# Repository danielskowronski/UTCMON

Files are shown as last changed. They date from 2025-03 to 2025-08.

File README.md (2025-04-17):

# UTCMON

Dual-screen clock intended designed mounting on top of *mon*itor (with USB camera in between), intended for displaying *UTC* and local time with proper NTP synchronization.

Project is baed on ESP32 for networking and 3.12" 256x64 OLED displays to match height of Logitech C920 camera. It'll additionaly include 3D printed cases for displays and central unit, light sensor for brightness, minimalistic physical controls and APIs for automation.

---

## Terminology, general ideas and assumptions

- Entire device consists of three units - 2 displays (left and right, both housing identical set of sensors, one large display and connector) and central unit (with ESP32 dev board, connectors and USB-C cable for power, debug and flashing).
- Display units are symmetrical in Y axis, intended to be placed in one line on top of computer monitor, separated by webcam, which is not part of the project. Connectors should be on inner edge of display units.
- This is a one-off, so standards are ajusted for prototype. No proper PCB is planned at this time.

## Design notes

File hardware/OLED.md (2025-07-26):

# OLED - 256x64 with SSD1322

- Controller: SSD1322
- OLED Display 3.12" 256*64 25664 Dots Graphic LCD Module Display Screen LCM Screen SSD1322 Controller Support SPI
- https://www.aliexpress.com/item/1005007321062605.html
- datasheet of controller: https://www.displayfuture.com/Display/datasheet/controller/SSD1322.pdf
- comes configured as parallel 80XX, using here as "4SPI" so need to swap jumper from R6 to R5
- SPI connection from ESP32 works with frequencies up to 39.999 MHz

## PINS used

- 01: 3V3
- 02: GND
- 03: SCLK
- 05: SDI/MOSI
- 14: DC (data/command)
- 15: RESET
- 16: CS (chip select)

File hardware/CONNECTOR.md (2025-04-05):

# Connector between L/R display boards and main MCU board

The connector is IDC10, one per display board.

Colour of pin on drawing = colour of Kynar cable on board and Dupont wires on prototype phase.

For pins split in two:

- bottom half is Kynar/Dupont colour
- top half is alternative colour on hand drawn schematics

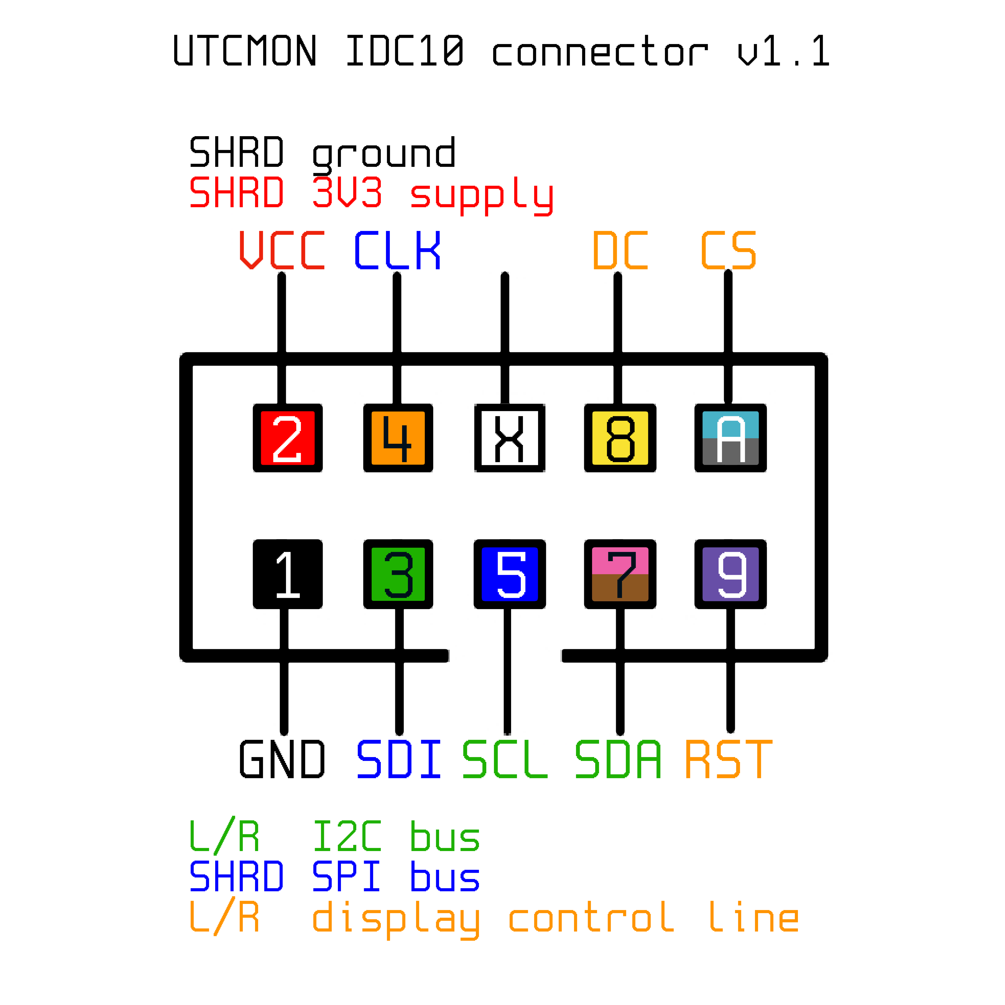
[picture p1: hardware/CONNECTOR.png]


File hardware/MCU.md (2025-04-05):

# MCU - ESP32S

- ID in Arduino: `NodeMCU-32S`
- ESP32S-CP2102-TYPE C (38pin)
- https://www.aliexpress.com/item/1005006161858012.html?spm=a2g0o.order_list.order_list_main.11.74fb1802DASUqN

## pin numbers for buses

- 18: VSPI SCLK
- 23: VSPI MOSI/SDI

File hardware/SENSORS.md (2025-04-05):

# Sensors

- all current sensors use I2C
- each display board (left and right) use separate I2C bus as one sensor (VL53L0X) has no hardware control; moreover two some separate lines for displays are needed anyway and ESP32 has two I2C

Buses:

- LEFT:
  - SDA: 21
  - SCK: 22
- RIGHT:
  - SDA: 32
  - SCK: 33

## Light sensor - TSL2561

- 2x TSL2561 - one per board
- I2C address 0x39 on both
- oriented towards top of unit
- used to set display brightness by averaging lux value and adjusting to 0..255 arnge

## Luminosity sensor - VL53L0X

- 2x VL53L0X - one per board
- I2C address 0x52 on both
- oriented towards front of unit
- used as touchless buttons (to avoid pushing displays from monitor) and primitive presence sensor

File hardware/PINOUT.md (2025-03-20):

# PINOUT

## prototype phase

common SPI bus for both displays:

- 3V3
- GND
- SCLK
- SDI/MOSI

1st display:

- DC => GPIO 00
- RESET => GPIO 04
- CS => 05

2nd display:

- DC => 02
- RESET => GPIO 16
- CS => 17

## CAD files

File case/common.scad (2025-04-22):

include <BOSL2/std.scad>
include <BOSL2/screws.scad>

$fa = 1;
$fs = 0.5;
$fn=36;

back_board_screw_dia=2;
back_board_screw_offset=1.75; //2?
back_board_thickness=1.5;

module base_plate_screw(){
    //TODO: autolmate offset
//    cylinder(wall_thickness, back_board_screw_dia/2, back_board_screw_dia/2);
    color("red")
    translate([0,0,wall_thickness+rnd/3])
    screw_hole("M2,10",head="flat",counterbore=0,anchor=TOP);
}

module base_plate(x_offset=0){
    difference(){
        cuboid([total_width, total_height, wall_thickness], anchor=[-1,-1,-1], rounding=rnd, edges=[TOP, "Z"]); // main front/back
        //cube([total_width, total_height, wall_thickness]); // main front/back

        translate([(total_width-back_board_width)/2+back_board_screw_offset+x_offset,(total_height-back_board_height)/2+back_board_screw_offset,0]) base_plate_screw(); 
        translate([(total_width+back_board_width)/2-back_board_screw_offset+x_offset,(total_height-back_board_height)/2+back_board_screw_offset,0]) base_plate_screw();
        translate([(total_width-back_board_width)/2+back_board_screw_offset+x_offset,(total_height+back_board_height)/2-back_board_screw_offset,0]) base_plate_screw();
        translate([(total_width+back_board_width)/2-back_board_screw_offset+x_offset,(total_height+back_board_height)/2-back_board_screw_offset,0]) base_plate_screw();

    }

}

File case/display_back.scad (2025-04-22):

include <display_common.scad>;

module display_back(){
    base_plate();
    
    //top wall
    translate([wall_thickness,0,-bottom_wall_top]) {
        difference(){
            cube([total_width-2*wall_thickness,wall_thickness, bottom_wall_top]);
            translate([(total_width-back_board_width)/2+lux_sensor_board_offset_from_back_board_x-wall_thickness,wall_thickness-lux_sensor_board_problematic_deth,0])
                color("red")cube([lux_sensor_board_width, lux_sensor_board_problematic_deth,bottom_wall_top ]);
        }
    }
    
    //right wall
    translate([total_width-wall_thickness,0,-bottom_wall_right]) {
        //cube([wall_thickness,total_height-wall_thickness, bottom_wall_right]);
        cuboid([wall_thickness,total_height-wall_thickness, bottom_wall_right], anchor=[-1,-1,-1], rounding=rnd, edges=[FRONT+RIGHT]);
        }
        
}

display_back();

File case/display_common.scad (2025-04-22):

include <common.scad>

// design for LEFT display board, mirror in slicer
// 0,0 = left-bottom (side of distance sensor)



total_width=150;
total_height=40;
wall_thickness=2;
wall_full=5+back_board_thickness+10; // between inside of front and back = 5+10+5 (distance/standoffs) + 1.5mm (board thickness)

display_window_width=79;
display_window_height=22;
//display_window_offset_from_bottom=7; // FIXME!
display_window_offset_y=-1; // it's not centered

display_board_width=100.6;
display_board_height=33.5;
display_board_screw_dia=3;
display_board_screw_offset_x=2.825; //??
display_board_screw_offset_y=2.0; //??

back_board_width=140.25;
back_board_height=30;

distance_sensor_board_offset_from_back_board_x=9; 
distance_sensor_board_offset_from_back_board_y=0;
distance_sensor_board_distance_between_bolts=20;
distance_sensor_window_heigh=4.5;
distance_sensor_window_width=2.5;
distance_sensor_window_offset_x=0.4;
distance_sensor_window_offset_y=-0.1;


lux_sensor_window_offset_from_back_board_x=-10.5;
lux_sensor_window_offset_from_front=4;
lux_sensor_window_width=3;
lux_sensor_window_height=5;

lux_sensor_board_offset_from_back_board_x=3; // true: 4
lux_sensor_board_width=15.5; // true: 14
lux_sensor_board_problematic_deth=1;

connector_height=9;
connector_width=20.75; // <-- was 20.5
connector_offset_from_back_board_z=3.5;

front_wall_right = 14.5;
front_wall_left = wall_full;
front_wall_bottom = wall_full;
front_wall_top = lux_sensor_window_offset_from_front+lux_sensor_window_height;

bottom_wall_right =  wall_full-front_wall_right;
bottom_wall_top =  wall_full-front_wall_top;

rnd = wall_thickness/2;

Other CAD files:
case/display_front.scad
case/main_back.scad
case/main_common.scad
case/main_front.scad

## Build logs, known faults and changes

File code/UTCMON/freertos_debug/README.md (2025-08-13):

```
export PROJBASE
```

1. clone https://github.com/espressif/esp32-arduino-lib-builder
2. without venv: `./install.sh`
3. `./build.sh -t esp3`

/Users/daniel/projects/UTCMON/espressif32/esp32-arduino-lib-builder/out/tools/esp32-arduino-libs/esp32/lib/libfreertos.a
/Users/daniel/.platformio/packages/framework-arduinoespressif32-libs/esp32/lib/libfreertos.a

cp /Users/daniel/projects/UTCMON/espressif32/esp32-arduino-lib-builder/build/esp-idf/freertos/libfreertos.a /Users/daniel/.platformio/packages/framework-arduinoespressif32-libs/esp32/lib/libfreertos.a
daae2e51d88c1c90440bbd24f5b0fb6cbd068aa29a2b764760a4bd04f360f68f  /Users/daniel/.platformio/packages/framework-arduinoespressif32-libs/esp32/lib/libfreertos.a
669c28799b5f1fc2cb5d08103088fd04c349c8a18e7286cf99dab9cc18b86ff3  /Users/daniel/.platformio/packages/framework-arduinoespressif32-libs/esp32/lib/libfreertos.a.orig

pio run --target clean
pio run --target uplaod && pio device monitor

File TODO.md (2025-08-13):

# ToDo

internal reference: `DSx2500A`

## MVP

2025-03 - 2025-04

- [x] project design, parts planning and shopping
- [x] validate all parts and their libraries: dual displays, distance sensors, light sensors
- [x] plan circuits including pinouts, solder everything and test
- [x] implement prototype code
- [x] convert to platformio
- [x] initial clock drawing
- [x] initial NTP sync (+WiFi)
- [x] full planned clock drawing
- [x] commit hardware diagrams and docs
- [x] 3D case - base unit and displays
- [x] handle light sensors for brightness
- [x] debug display distance sensors
- [x] validate assembled unit

## first improvements

2025-04 - 2025-07

- [x] splash screen with debug info
- [x] stabilize distance sensors
- [.] stabilize display (long term tests)
  - [x] observation and research
  - [x] periodic screen redraw
  - [x] frequency and setup
  - [x] workaround for SPI transmission broken due to other cores triggering inetrrupts
  - [.] further SPI issue diagnostics
  - [ ] fix SPI transmission in u8g2  https://github.com/olikraus/u8g2/issues/2682
  - [x] reduce data updates when not needed: simple per-screen
  - [ ] reduce data updates when not needed: segments

## current work

2025-07 - ...

- [x] controllable NTP sync
- [x] NTP drift detection
- [x] WiFi reconnect after ESP_ERR_WIFI_CONN reinits NTP client, which fails assertion `assert failed: sntp_setoperatingmode /IDF/components/lwip/lwip/src/apps/sntp/sntp.c:748 (Operating mode must not be set while SNTP client is running)` and crashes device
- [x] add icon to indicate wifi connection is lost
- [.] drawClock - all magic numers defined in UI.h as UIL/UIR
- [ ] rest of UI drawing - all magic numers defined in UI.h as UIL/UIR
- [ ] move TimeSync contents to some class
- [x] standardize debug messages on console
- [ ] improve code as of 2025-W30 (remove warnings, duplicates)
- [.] improve UI render formatting
- [ ] cover all places where we could check init status, attempt checking display update status 
- [-] better brightness control (without flicker) -> can't be done better
- [x] distance sensor - wrap in structs, fix logging and formatting
- [ ] light sensor - wrap in structs, fix logging and formatting
- [x] distance sensors / virtual buttons - stabilize output, debug print and display marker for tests
- [x] timezone change UI - virtual buttons
- [x] brightness control UI - virtual buttons
- [ ] watchdog for abnormal NTP sync -> reboot
- [ ] invert screen by calling A7/A6 commands instead of draw color swapping (but need to track it)

## future work

- [ ] add logging to loki or similar system
- [ ] multithread operations??
- [ ] runtime control via WebAPI (timezone, timezones, display mode, brightness, schedules...)
- [ ] sensor status push via MQTT
- [ ] countdown mode
- [ ] multi-TZ mode
- [ ] simple text info pull from external server mode

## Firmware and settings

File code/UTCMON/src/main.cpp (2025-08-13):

#include <Arduino.h>
#include <esp_wifi.h>
#include "hw_config.h"
#include "sys_config.h"
#include "DateTime.h"
#include "UI.h"
#include "LightSensors.h"
#include "common.h"
#include <SPI.h>
#include <WiFi.h>
#include <AceTime.h>
#include <time.h>
#include <string>
#include <cstdio>
#include <cstdint>
#include "debug.h"
#include <Wire.h>
#include "TimeSync.h"
#include "Logging.h"

void checkNtpDriftIfNeeded() {
  time_t now = time(nullptr);
  if (now - ntpDiagnostics.lastDriftCheck >= System::NTP::CheckPeriodS) {
    // no extra logging, checkNTP handles that
    checkNTP();
    // ntpDiagnostics.lastDriftCheck is set in checkNTP()
  }
}

DateTime dt;
UI ui(LeftBus::Display::config, RightBus::Display::config);
LightSensors light(LeftBus::LightSensor::config, RightBus::LightSensor::config);
DistanceSensors distance(LeftBus::DistanceSensor::config, RightBus::DistanceSensor::config, false);

void WiFiConnect(bool updateDisplay = false){
  while (true) {
    WiFi.begin(WIFI_SSID, WIFI_PASS);
    logger.info(TAG_NET, "Starting WiFi connection attempt to %s", WIFI_SSID);
    if (updateDisplay) ui.drawInitScreenNetPhase1(WIFI_SSID);

    int count=0;
    while (WiFi.status() != WL_CONNECTED) {
      logger.verbose(TAG_NET, "Waiting for WiFi to connect - attempt %4d/%d", count, System::Network::ConnCheckCount);
      delay(System::Network::ConnCheckPeriodMs);
      count++;
      if (count > System::Network::ConnCheckCount) {
        //logger.warn(TAG_NET, "Failed to connect to WiFi");
        break;
      }
    }
    if (WiFi.status() != WL_CONNECTED) {
      logger.warn(TAG_NET, "Failed to connect to WiFi");
      continue;
    }
    logger.info(TAG_NET, "WiFi connected, obtained IP address: %s", WiFi.localIP().toString().c_str());

    if (updateDisplay) ui.drawInitScreenNetPhase2(WiFi.localIP().toString());
    esp_wifi_set_ps(WIFI_PS_NONE); // TODO: parametrize this

    logger.info(TAG_NET, "Starting initial NTP sync to: %s", System::NTP::ServerHost);
    configTimeExtended(0, 0, System::NTP::ServerHost);
    struct tm timeinfo;
    if (updateDisplay) ui.drawInitScreenNetPhase3();
    while (!getLocalTime(&timeinfo)) {
      logger.debug(TAG_NET, "Waiting for initial NTP to finish");
      delay(1000);
    }
    checkNTP();
    if (updateDisplay) ui.drawInitScreenNetPhase4(ntpDiagnostics.lastDriftMs);
    break;
  } 
}

void WiFiStationDisconnected(WiFiEvent_t event, WiFiEventInfo_t info){
  logger.warn(TAG_NET, "WiFi disconnected with event %d and reason", event, info.wifi_sta_disconnected.reason);
  WiFiConnect();
}


// TODO: introduce some struct to hold all displayTask state variables
int avg_lux;
int contrast=255;
int lux_l; // only for debug phase
int lux_r; // only for debug phase
DateTimeStruct dts;
DistanceStatusPair dsp;
size_t currentTz = 0;
const char* nextTimezone() {
  currentTz = (currentTz + 1) % System::DisplayModes::timezones_count;
  return System::DisplayModes::timezones[currentTz];
}

TaskHandle_t displayHandle = NULL;
void UTCMON_displayTask(void* pvParameters) {
  (void)pvParameters;
  for (;;) {
    DateTimeStruct dts = dt.getDateTimeStruct();

    checkNtpDriftIfNeeded();
    
    dsp = distance.getSensorsStatus();

    if (dsp.left.triggering && dsp.left.triggeringCounter == 1) {
      ui.setCommonDisplayMode(CommonDisplayMode((ui.getCommonDisplayMode()+1)%CommonDisplayMode::Count));
      logger.info(TAG_VBUTTONS, "Left vbutton triggered, mode changed to %s", ui.commonDisplayModeName(ui.getCommonDisplayMode()));
    }
    if (dsp.right.triggering && dsp.right.triggeringCounter == 1) {
      if (ui.getCommonDisplayMode() == CommonDisplayMode::Blank) {
        logger.info(TAG_VBUTTONS, "Right vbutton triggered but screen blanked so not taking action");
      }
      else {
        dt.changeTimezone(nextTimezone());
        dts = dt.getDateTimeStruct();
        logger.info(TAG_VBUTTONS, "Right vbutton triggered, timezone changed to %s", dts.timezone.c_str());
      }
    }


    lux_l = light.getLeft();
    lux_r = light.getRight();
    avg_lux = light.getAvg();

    if (avg_lux > 512) contrast = 255;
    else contrast = int(avg_lux / 2);
    //logger.verbose(TAG_SENSORS, "distL=%s distR=%s | luxL=%5d luxR=%5d cont=%3d", fmtDist(mm_l), fmtDist(mm_r), lux_l, lux_r, contrast); // FIXME: move to separare function / class

    ui.setContrast(contrast);
    ui.drawClock(dts, dsp, lux_l, lux_r);

    vTaskDelay(pdMS_TO_TICKS(System::Loops::DisplayTaskPeriodMs));
  }
}



// TODO: split to threads - one for clock, one for sensors
void loop() { 
  loopCheckPinMux();

  #ifdef STRESS_TEST_WIFI
  rotateWiFiPsMode();
  #endif

  if (WiFi.status() != WL_CONNECTED) {
    WiFiConnect();
  }

  //ui.setCommonDisplayMode(CommonDisplayMode((ui.getCommonDisplayMode()+1)%CommonDisplayMode::Count)); // BUG

  vTaskDelay(pdMS_TO_TICKS(System::Loops::LoopTaskPeriodMs));
}

void setup() {
  sys_config_overrides();

  Serial.begin(CommonBus::Serial::Baudrate);
  while(!Serial); logger.forwardTo(&Serial);
  logger.setLevel(System::Logging::Level); 
  Mycila::Logger::setTimeProvider([]() -> uint32_t {
    return time(nullptr);
  });

  SPI.begin(CommonBus::SPI::SCK, CommonBus::SPI::MISO, CommonBus::SPI::MOSI);
  SPI.setFrequency(CommonBus::SPI::Frequency);
  // TODO: Wire+Wire1 vs custom TwoWire instances; per-class vs global
  Wire.begin(LeftBus::I2C::SDA, LeftBus::I2C::SCL);
  Wire1.begin(RightBus::I2C::SDA, RightBus::I2C::SCL);

  ui.init(); // TODO: check init success
  ui.drawSplashScreen(VER_INFO);

  DevicePairInitSuccess lightInitSuccess = light.init();
  DevicePairInitSuccess distanceInitSuccess = distance.init();

  ui.drawInitScreenSensor(VER_INFO, distanceInitSuccess.left, lightInitSuccess.left, distanceInitSuccess.right, lightInitSuccess.right);
  // TODO: if any init fails, attempt system restart
  if (!(distanceInitSuccess.left) || !(lightInitSuccess.left) || !(distanceInitSuccess.right) || !(lightInitSuccess.right)) {
    logger.error(TAG_SYS, "Failed to initialize one or more sensors, restarting system -> dist_l: %d, dist_r: %d, light_l: %d, light_r: %d",
      distanceInitSuccess.left, distanceInitSuccess.right,
      lightInitSuccess.left, lightInitSuccess.right
    );
    delay(5000);
    ESP.restart();
  }

  WiFiConnect(true);
  //WiFi.onEvent(WiFiStationDisconnected, WiFiEvent_t::ARDUINO_EVENT_WIFI_STA_DISCONNECTED);

  #ifdef STRESS_TEST_U8G2
  ui.debugLoop();
  #endif

  #ifdef STRESS_TEST_CLOBBER
  startRmtClobber(5);
  #endif

  reconfigureSpiDrive(GPIO_DRIVE_CAP_3); // TODO: parametrize this via hw_config

  setupCheckPinMux();
  
  delay(2000);
  xTaskCreatePinnedToCore(
    UTCMON_displayTask,    // function
    "Display",             // name
    8192,                  // stack size in bytes
    NULL,                  // parameters
    configMAX_PRIORITIES-1,// priority
    &displayHandle,        // task handle
    1                      // run on core; 1=app, 0=system/wifi
  );

  dt=DateTime(System::DisplayModes::timezones[0]);
  ui.setDateDisplayMode(DateDisplayMode::FullAndNTP);
  //ui.setDateDisplayMode(DateDisplayMode::FullAndSensors);
}

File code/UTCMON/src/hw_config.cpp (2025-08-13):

#include "hw_config.h"

namespace LeftBus
{
  namespace I2C
  {
    const uint32_t Frequency = 100 * kHz;
  }
  namespace LightSensor
  {
    const LightSensorConfig config = {
        .I2CAddress = 0x39,
        .DebugEnabled = false,
        .AutoRangeEnabled = true,
        .IntegrationTime = TSL2561_INTEGRATIONTIME_13MS,
        .Gain = TSL2561_GAIN_16X};
  }
  namespace DistanceSensor
  {
    const DistanceSensorConfig config = {
        .I2CAddress = 0x29,
        .DebugEnabled = false,
        .Mode = Adafruit_VL53L0X::VL53L0X_SENSE_HIGH_SPEED,
        .TriggeringHoldUs = 350 * 1000, // 350ms
        .TriggeringThreshold = 100,     // 10cm
        .TriggeringIgnore = 20,         // 2cm
        .alias = "LEFT "};
  }
  namespace Display
  {
    const DisplayConfig config = {
        .Frequency = SPI_FREQUENCY,
        .CS = 5,
        .DC = 0,
        .RESET = 4};
  }
}

namespace RightBus
{
  namespace I2C
  {
    const uint32_t Frequency = 100 * kHz;
  }
  namespace LightSensor
  {
    const LightSensorConfig config = {
        .I2CAddress = 0x39,
        .DebugEnabled = false,
        .AutoRangeEnabled = true,
        .IntegrationTime = TSL2561_INTEGRATIONTIME_13MS,
        .Gain = TSL2561_GAIN_16X};
  }
  namespace DistanceSensor
  {
    const DistanceSensorConfig config = {
        .I2CAddress = 0x29,
        .DebugEnabled = false,
        .Mode = Adafruit_VL53L0X::VL53L0X_SENSE_HIGH_SPEED,
        .TriggeringHoldUs = 350 * 1000, // 350ms
        .TriggeringThreshold = 100,     // 10cm
        .TriggeringIgnore = 20,         // 2cm
        .alias = "RIGHT"};
  }
  namespace Display
  {
    const DisplayConfig config = {
        .Frequency = SPI_FREQUENCY,
        .CS = 25,
        .DC = 26,
        .RESET = 27};
  }
}

namespace CommonBus
{
  namespace Serial
  {
    const uint32_t Baudrate = 115200;
  }
  namespace SPI
  {
    const uint32_t Frequency = SPI_FREQUENCY;
    const int8_t MOSI = 23; // VSPI MOSI pin
    const int8_t MISO = 19; // VSPI MISO pin
    const int8_t SCK = 18;  // VSPI SCLK pin
  }
}

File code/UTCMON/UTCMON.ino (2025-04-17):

#define VER_INFO "v0.2.0 2025-04-09"
#include <SPI.h>
#include <U8g2lib.h>
#include <WiFi.h>
#include <AceTime.h>
#include <time.h>
#include "Secrets.h"

#include <Wire.h>
#include <Adafruit_VL53L0X.h>
#include <Adafruit_Sensor.h>
#include <Adafruit_TSL2561_U.h>


using namespace ace_time;
static const int CACHE_SIZE = 3;
static ExtendedZoneProcessorCache<CACHE_SIZE> zoneProcessorCache;
static ExtendedZoneManager manager(
    zonedbx::kZoneAndLinkRegistrySize,
    zonedbx::kZoneAndLinkRegistry,
    zoneProcessorCache);

TwoWire I2C_l = TwoWire(0);
TwoWire I2C_r = TwoWire(1);

Adafruit_VL53L0X lox_l = Adafruit_VL53L0X();
Adafruit_VL53L0X lox_r = Adafruit_VL53L0X();

Adafruit_TSL2561_Unified tsl_l = Adafruit_TSL2561_Unified(0x39);
Adafruit_TSL2561_Unified tsl_r = Adafruit_TSL2561_Unified(0x39);

U8G2_SSD1322_NHD_256X64_F_4W_HW_SPI u8g2_l(U8G2_R0, /* cs=*/ 5, /* dc=*/ 0, /* reset=*/ 4);
U8G2_SSD1322_NHD_256X64_F_4W_HW_SPI u8g2_r(U8G2_R0, /* cs=*/ 25, /* dc=*/ 26, /* reset=*/ 27);


int computeIsoWeekNumber(int year, int month, int day) {
  // Build a tm structure for the given date at noon to avoid DST edge issues.
  struct tm tmDate = {0};
  tmDate.tm_year = year - 1900;
  tmDate.tm_mon  = month - 1;
  tmDate.tm_mday = day;
  tmDate.tm_hour = 12;
  mktime(&tmDate);

  // Determine ISO weekday (Monday=1, Tuesday=2, …, Sunday=7)
  int isoWeekday = (tmDate.tm_wday == 0) ? 7 : tmDate.tm_wday;

  // Shift the date to the Thursday of the current week.
  time_t t = mktime(&tmDate);
  time_t t_thursday = t + (4 - isoWeekday) * 86400; // 86400 seconds per day
  struct tm tmThursday;
  localtime_r(&t_thursday, &tmThursday);
  int isoYear = tmThursday.tm_year + 1900;

  // Compute January 4th of the ISO year.
  struct tm tmJan4 = {0};
  tmJan4.tm_year = isoYear - 1900;
  tmJan4.tm_mon  = 0; // January
  tmJan4.tm_mday = 4;
  tmJan4.tm_hour = 12;
  mktime(&tmJan4);
  int jan4IsoWeekday = (tmJan4.tm_wday == 0) ? 7 : tmJan4.tm_wday;

  // Find the Monday of the week containing January 4 (the start of week 1).
  time_t t_monday = mktime(&tmJan4) - (jan4IsoWeekday - 1) * 86400;

  // Compute the week number as the number of whole weeks between t_monday and t_thursday.
  int weekNumber = 1 + ((int)(t_thursday - t_monday) / 86400) / 7;
  return weekNumber;
}


void drawClock(int year, int month, int day, int week, const char* weekday, int hour, int minute, int second, const char* timezone, int mm_l, int mm_r, int lux_l, int lux_r){
  char buffer[256];

  u8g2_l.clearBuffer();

  // Left screen, bottom line, large: YYYY-MM-DD
  sprintf(buffer, "%04d-%02d-%02d", year%10000, month%100, day%100);
  u8g2_l.setFont(u8g2_font_logisoso38_tn);
  u8g2_l.drawStr(0,64,buffer);

  // Left screen, top line, small: ISO week - Weekeday
  sprintf(buffer, "W%02d %.16s", week, weekday);
  u8g2_l.setFont(u8g2_font_logisoso16_tr);
  u8g2_l.drawStr(0,20,buffer);

  // Left screen, top line, small: distance
  if (mm_l<=2500) sprintf(buffer, "% 4d.%d cm", int(mm_l/10), mm_l%10); else sprintf(buffer, " >>>>> cm");
  u8g2_l.setFont(u8g2_font_t0_12_tr);
  u8g2_l.drawStr(140,10,buffer);
  sprintf(buffer, "% 6d lx", lux_l);
  u8g2_l.setFont(u8g2_font_t0_12_tr);
  u8g2_l.drawStr(140,20,buffer);


  if (mm_r<=2500) sprintf(buffer, "% 4d.%d cm", int(mm_r/10), mm_r%10); else sprintf(buffer, " >>>>> cm");
  u8g2_l.setFont(u8g2_font_t0_12_tr);
  u8g2_l.drawStr(200,10,buffer);
  sprintf(buffer, "% 6d lx", lux_r);
  u8g2_l.setFont(u8g2_font_t0_12_tr);
  u8g2_l.drawStr(200,20,buffer);

  u8g2_l.sendBuffer();

  u8g2_r.clearBuffer();

  // Right screen, bottom line, large: HH:MM
  sprintf(buffer, "%02d:%02d", hour%100, minute%100);
  u8g2_r.setFont(u8g2_font_logisoso62_tn);
  u8g2_r.drawStr(0,64,buffer);

  // Right screen, bottom line continued, medium: :SS
  sprintf(buffer, ":%02d", second%100);
  u8g2_r.setFont(u8g2_font_logisoso46_tn);
  u8g2_r.drawStr(5*36,64,buffer);

  // Right screen, top line, above :SS, small: timezone
  sprintf(buffer, "%.4s", timezone);
  u8g2_r.setFont(u8g2_font_logisoso16_tr);
  u8g2_r.drawStr(5*36+26+5*(strlen(timezone)%2),16,buffer);

  u8g2_r.sendBuffer();
}


void setup() {
  Serial.begin(115200);

  WiFi.begin(WIFI_SSID, WIFI_PASS);

  SPI.setFrequency(15000000);
  u8g2_l.setBusClock(15000000);
  u8g2_r.setBusClock(15000000);
  u8g2_l.begin();
  u8g2_r.begin();

  u8g2_l.clearBuffer();
  u8g2_l.drawBox(0,0,256,64);
  u8g2_l.setDrawColor(0);
  u8g2_l.setFont(u8g2_font_logisoso32_tr);
  u8g2_l.drawStr(0,32,"UTCMON Left");
  u8g2_l.setFont(u8g2_font_profont17_mr);
  u8g2_l.drawStr(0,60,VER_INFO);
  u8g2_l.setDrawColor(1);
  u8g2_l.sendBuffer();
  

  u8g2_r.clearBuffer();
  u8g2_r.drawBox(0,0,256,64);
  u8g2_r.setDrawColor(0);
  u8g2_r.setFont(u8g2_font_logisoso32_tr);
  u8g2_r.drawStr(0,32,"UTCMON Right");
  u8g2_r.setFont(u8g2_font_profont17_mr);
  u8g2_r.drawStr(0,60,"Initializing................................");
  u8g2_r.setDrawColor(1);
  u8g2_r.sendBuffer();

  Wire.begin(21, 22);
  Wire1.begin(32, 33);
  I2C_l.begin(21, 22, 100000);
  I2C_r.begin(32, 33, 100000); 

  delay(250);
  bool lox_ok_l = lox_l.begin(0x29, false, &Wire);
  Serial.printf("lox_l.begin() %1d\n", lox_ok_l);
  if (lox_ok_l) lox_l.configSensor(Adafruit_VL53L0X::VL53L0X_SENSE_HIGH_SPEED);
  delay(250);
  bool lox_ok_r = lox_r.begin(0x29, false, &Wire1);
  Serial.printf("lox_r.begin() %1d\n", lox_ok_r);
  if (lox_ok_r) lox_r.configSensor(Adafruit_VL53L0X::VL53L0X_SENSE_HIGH_SPEED);
  delay(250);

  bool tsl_ok_l = tsl_l.begin(&Wire);
  Serial.printf("tsl_l.begin() %1d\n", tsl_ok_l);
  delay(250);
  bool tsl_ok_r = tsl_r.begin(&Wire1);
  Serial.printf("tsl_r.begin() %1d\n", tsl_ok_r);
  delay(250);

  char buffer[256];
  u8g2_l.clearBuffer();
  u8g2_l.drawStr(0,20,"UTCMON ver: ");u8g2_l.drawStr(100,20,VER_INFO);
  u8g2_l.drawStr(0,40,"Dist. sensors: ");
  if (lox_ok_l) u8g2_l.drawStr(130,40,"_OK_"); else u8g2_l.drawStr(130,40,"FAIL"); 
  if (lox_ok_r) u8g2_l.drawStr(180,40,"_OK_"); else u8g2_l.drawStr(180,40,"FAIL"); 
  u8g2_l.drawStr(0,60,"Light sensors: ");
  if (tsl_ok_l) u8g2_l.drawStr(130,60,"_OK_"); else u8g2_l.drawStr(130,60,"FAIL"); 
  if (tsl_ok_r) u8g2_l.drawStr(180,60,"_OK_"); else u8g2_l.drawStr(180,60,"FAIL"); 
  u8g2_l.sendBuffer();


  u8g2_r.clearBuffer();
  u8g2_r.setFontMode(0);
  u8g2_r.setDrawColor(1);
  u8g2_r.drawStr(0,20,"SSID: ");
  u8g2_r.drawStr(48,20,WIFI_SSID);
  u8g2_r.sendBuffer();


  while (WiFi.status() != WL_CONNECTED) {
    Serial.println("Connecting ...");
    u8g2_r.drawStr(0,40,"Wi-Fi connecting...");
    u8g2_r.sendBuffer();
    delay(500);
    }
  


  u8g2_r.drawStr(0,40,"Wi-Fi connected       ");
  u8g2_r.sendBuffer();
  Serial.println("Connected");
  configTime(0, 0, "pool.ntp.org");
  struct tm timeinfo;
  while (!getLocalTime(&timeinfo)) {

    u8g2_r.drawStr(0,60,"NTP initiliazing...");
    u8g2_r.sendBuffer();
    Serial.println("Waiting for time sync...");
    delay(1000);
  }
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

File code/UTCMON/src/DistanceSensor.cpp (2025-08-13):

#include "DistanceSensor.h"
#include "Logging.h"

DistanceSensor::DistanceSensor()
{
  this->mockSensor = true;
}
DistanceSensor::DistanceSensor(DistanceSensorConfig config, TwoWire *i2c)
{
  this->config = config;
  this->i2c = i2c;
  this->mockSensor = false;
}
bool DistanceSensor::init()
{
  if (this->mockSensor)
  {
    return true;
  }

  if (!this->sensor.begin(this->config.I2CAddress, false, this->i2c))
  {
    logger.error(TAG_DIST, "%s Failed to find VL53L0X sensor at address 0x%02x on I2C bus %d", this->config.alias, this->config.I2CAddress, this->i2c->getBusNum());
    return false;
  }
  else
  {
    logger.info(TAG_DIST, "%s VL53L0X sensor initialized at address 0x%02x on I2C bus %d", this->config.alias, this->config.I2CAddress, this->i2c->getBusNum());
    this->sensor.configSensor(this->config.Mode);
    return true;
  }
}
int DistanceSensor::getDistance(bool debugEnabled)
{
  if (this->mockSensor)
  {
    return 2137; // mock value
  }

  this->sensor.rangingTest(&(this->measure), this->config.DebugEnabled || debugEnabled);
  if (measure.RangeStatus != 4)
  { // phase failures have incorrect data
    return measure.RangeMilliMeter;
  }
  else
  {
    return DISTANCE_ERROR;
  }
}
DistanceStatus DistanceSensor::getSensorStatus()
{
  DistanceStatus status;
  status.mm = this->getDistance();
  status.triggering = false;
  status.triggeringCounter = 0;

  bool currentTriggering = (status.mm < this->config.TriggeringThreshold) && (status.mm > this->config.TriggeringIgnore);

  // FIXME: improve how this logic is written
  uint64_t now = micros();
  if (currentTriggering)
  {
    if ((this->lastTriggeringTime != 0) && ((now - this->lastTriggeringTime) > this->config.TriggeringHoldUs))
    {
      status.triggering = true;
      this->triggerCounter++;
      status.triggeringCounter = this->triggerCounter;
      logger.debug(TAG_DIST, "%s Sensor triggering detected, distance: %s, time since last: %llu us, counter: %d", this->config.alias, fmtDist(status, false, true, true).c_str(), now - this->lastTriggeringTime, this->triggerCounter);
    }
    if (!(this->lastTriggering))
    {
      this->lastTriggeringTime = now;
    }
  }
  else
  {
    this->lastTriggeringTime = 0;
    this->triggerCounter = 0;
  }
  this->lastTriggering = currentTriggering;

  return status;
}
String DistanceSensor::fmtDist(DistanceStatus ds, bool preferMM, bool showUnit, bool showTriggering)
{
  String unit = showUnit ? (preferMM ? "mm" : "cm") : "";
  String triggerMark = showTriggering ? (ds.triggering ? "!" : ".") : "";

  if (ds.mm > DISTANCE_MAX || ds.mm == DISTANCE_ERROR)
  {
    String ret = preferMM ? "____" : "_____";
    if (ds.mm == DISTANCE_ERROR)
      ret = preferMM ? "----" : "-----";

    return ret + unit + triggerMark;
  }

  char buffer[11];
  if (preferMM)
  {
    sprintf(buffer, "%4d%s%s", ds.mm, unit.c_str(), triggerMark.c_str());
  }
  else
  {
    sprintf(buffer, "%3d.%d%s%s", ds.mm / 10, ds.mm % 10, unit.c_str(), triggerMark.c_str());
  }
  return String(buffer);
}

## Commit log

2025-03-20 prototype clock drawing (screens layout)
2025-04-05 connector, light and distance sensors
    - define connector between display boards and main MCU board (physically implemented, docs on boards TBD)
    - implement (previously tested) light and distance sensors
    - primitive version of brightness control
    - display distance and lux values to validate sensor status
    - sync hardware docs, add ToDo
2025-04-17 3D model of display case - final version
    squashed work on first square version with rounded corners for better look and print
    [display_back.scad, display_common.scad, display_front.scad]
2025-04-17 add splash screen and diagnostic info on screen
    - live measurement values of both light and distance sensors rendered in currently free space on left screen
    - splash screen with network and time init progress plus status of all sensors
2025-04-22 implement main unit case, move some code to common import
    [common.scad, display_back.scad, display_common.scad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]
2025-04-22 move light sensors to new class, add DevicePairInitSuccess struct
2025-04-23 move distance sensors to new class, backport generic for getLeft/Right into light
2025-07-22 mitigate one screen corruption and WiFi disconnects
    - bump u8g2 version
    - move screen sendBuffer to [no]interrupt guarded method
    - add extra screen redraw every hour (plus unix timestamp to DTS)
    - adjust SPI speed (15 MHz -> 300 kHz) and ensure VSPI pins
    - add option to mock light and distance sensors (one was broken)
    [UI.cpp, UI.h, main.cpp]
2025-07-22 controllable NTP sync and NTP drift detection
    - import ToDo doc
    - split hw_config to header and body to handle consts
    - add NTP config to hw_config
    - use ESP-IDF to handle NTP sync setup
    - use manual (S)NTP query to get drift
    - add date display mode switching: sensors/ntp/just date
    - adjust splash screen info (WiFi IP, NTP drift), tweak text rendering
    [UI.cpp, UI.h, hw_config.cpp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]
2025-07-22 logging
    - use enhanced MycilaLogger (pending PR)
    - logs with epoch time as timestamp, tags from fixed defines and colors
    - replaced all Serial.print with logger on relevant levels (level configurable from hw_config)
    - diagnostic print for distance and light sensors with formatting
    [hw_config.cpp, main.cpp]
2025-07-26 workaround for display glitches and minor fixes
    - identify platform framework versions available, pin one of them
    - keep all SPI frequencies the same in hw_config (they will anyway end up the same) and introduce aliast for kHz+MHz
    - test SPI frequencies and confirm 30 MHz is OK
    - extract main clock screen update lop to separate RTOS task so it can have priority and core pinning set
    - set it to highest priority on core with WiFi operation as workaround to ensure SPI is not interrupted
    - keep original loop() as place for detecting and triggering WiFi reconnect
    - fix logging of NTP diag (incorrect types)
    - introduce CS line testing for 1st display but keep it disabled
    - clarify OLED docs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
    [UI.cpp, hw_config.cpp, main.cpp]
2025-07-26 pack distance sensor values into structs and unify formatting
    - DistanceStatus struct with distance in mm and bool flag for triggering info (dependent on new value in hw_config)
    - DistanceStatusPair packing left and right DistanceStatus
    - new method DistanceSensors::getSensorsStatus() to get DistanceStatusPair and verbose-debug log values (not equal to Adafruit_VL53L0X's rangingTest's debug); this logging is moved from main loop()
    - static String method to format DistanceStatus
    - above method used in getSensorsStatus (as replacement from logging in displayTask)
    - it also replaces formatting done in UI::drawClock (+ DistanceStatusPair passed instead of 2x int)
    [UI.cpp, UI.h, hw_config.cpp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]
2025-07-26 SPI issues - sync latest attempts
    - bump platform to 55.03.30 as some issues were recently fixed in arduino-esp32
    - move back to original core 1 (non-WiFi) and disable no(Interrupts) to monitor ideal conditions
    - add extra debug logging to detect abnormal screen update time (absolute or jitter between two)
    - add extra debug to period NTP_DIAG log message to show uptime for crash logging
    [UI.cpp, UI.h, hw_config.cpp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]
2025-07-26 WiFi status handling, improve drawClock math
    - add WiFi offline/online icon to left display before week and weekday
    - replace magic numbers in drawClock that relate to left displa with series of aliases in UI.h
    - fix issue with NTP re-init after WiFi reconnect
    - disable updating screen for non-setup calls to WiFiConnect (this collided with displayTask, we now have icon to indicate network status and time is more important as WiFi can get stuck for minutes)
    - DistanceSensors::fmtDist can now format in mm or cm (mm used for displays to save on space)
    [UI.cpp, UI.h, main.cpp]
2025-07-28 base for handling virtual buttons, reduce screen rewrites
    base for handling virtual buttons (via distance sensors):
    - from class `DistanceSensors` extract `DistanceSensor` which is wrapper for `Adafruit_VL53L0X`, `TwoWire` pointer, `DistanceSensorConfig` and variables for tracking triggering; this achieves DRY and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
    - expand `DistanceSensorConfig` to have triggering threshold distance and hold time, as well as alias (for passing to logger functions)
    - from `hw_config` extract `System` namespace into `sys_config` and move loop delay configs there
    reduce screen rewrites (UI):
    - split `drawClock` to date (+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
2025-07-30 first virtual buttons - toggle blank, change timezone
    - tweak distance sensor trigger distance and time + displayTak loop delay
    - support cycling through predefined timezones to be used in drawCloc, add them to sys_config
    - support display blanking in drawing routines (via new method)
    - implement reaction to left and right virtual buttons: toggle blank, select next timezone
2025-08-11 various debug and stress test modes, tweak virtual buttons, thin font drawing mode
    - debug and stress test modes to support debugging SPI comms issues including validation of pin config and setting pin drive current
    - set WiFi power saving mode to none (doesn't make sense to sleep if we fire UDP every minute)
    - add minimum triggering distance for virtual buttons to get rid of false positives (0mm fire from time to time, setting 1cm since 3cm seems to be minimum); also tweak triggering time to 150ms
    - Logisoso 38 and 62: add manually edited variant that's hollowed out + "original" since my toolset generates BMF from TTF and glyphs are not 1:1 with u8g2
    - add new enum for left virtual button t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
    [DistanceSensor.cpp, UI.cpp, UI.h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]
2025-08-13 u8g2 SPI debugging and minor fixes
    ref: https://github.com/olikraus/u8g2/issues/2682
    - optional initial debug controls over UART to issue direct SSD1322 commands, stress test display and intentionally enable injecting unpextected A0h commands mid-transfer (most of code is temporary and machine-generated)
    - extract u8x8_d_ssd1322.c and commit here to allow command injection and quick timing param tweaking tweaking of u8g2; also script to patch it into libs
    - tweak build date script to include time and inject it to logger tags (for UART recorder)
    - revert recent change to decrease trigger time of virtual buttons
    - fix bug where sys_config_overrides didn't work
    - format code
    [DistanceSensor.cpp]
